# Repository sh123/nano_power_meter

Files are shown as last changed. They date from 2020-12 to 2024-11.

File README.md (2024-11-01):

# Introduction
Dual channel Arduino Nano RF milliwatt power meter for HF/VHF/UHF/SHF bands. Can be used for power measurement, different RF equipment troubleshooting, RF leakage search and antenna radiation/gain measurements and comparison.

This project is Arduino Nano clone of W1GHZ power meter adopted for use with Arduino Nano and SSD1307 OLED screen. Read more details at http://www.w1ghz.org/new/portable_powermeter.pdf.

Unlike original meter, which is just an indicator, this device shows precise dBm values and could be calibrated, calibration table is stored in the sketch. Moreover, device takes maximum RF power value during 1 second interval, which allows signal duration measurements down to 1 ms and marks maximum value during 1 minute interval on the bar.

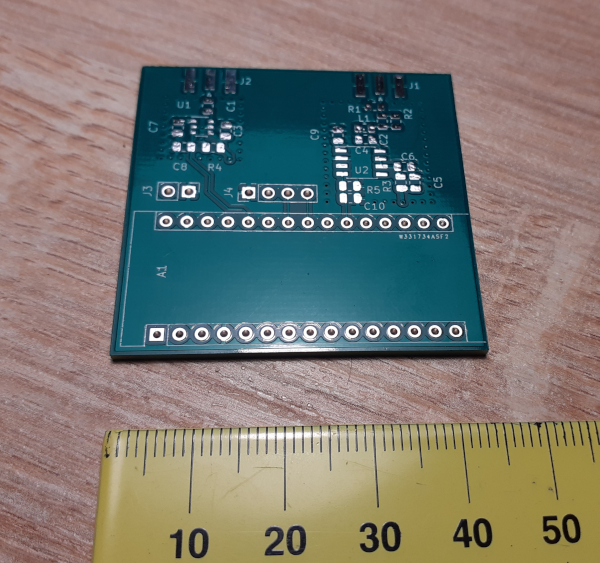
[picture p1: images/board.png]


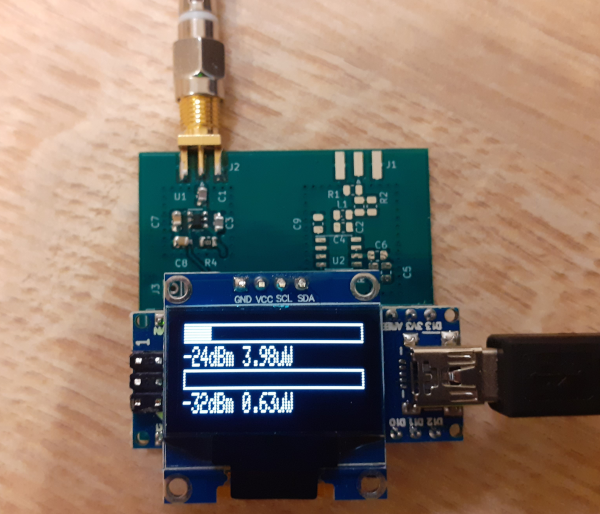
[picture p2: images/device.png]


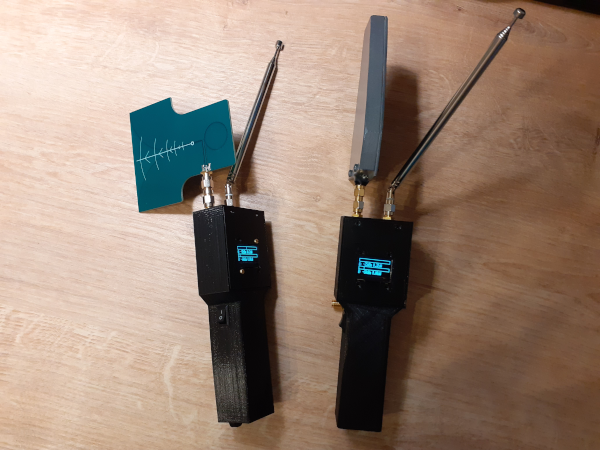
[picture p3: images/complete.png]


# Technical details
- Measurement power range from -32 up to 20 dBm on channel A and -60 up to 20 dBm on channel B, with external attenuator could be used for larger values.
- Frequency range
  - Channel A: 300 MHz - 7 GHz, up to 12 GHz with performance degradation
  - Channel B: 10 KHz up to 300 MHz
- Minimum signal length detection about 1 ms
- Based on Arduino Nano
- Screen is [SSD1307](https://cdn-shop.adafruit.com/datasheets/SSD1306.pdf)
- UHF/SHF part (left channel A) is based [LTC5507 RF Power Detector](https://www.analog.com/media/en/technical-documentation/data-sheets/5508fa.pdf), allows measurement from 300MHz up to 7GHz and up to approximately 12 GHz with some performance degradation.
- HF/VHF part (right channel B) is based on [AD8307 Logarithmic Amplifier](https://www.analog.com/media/en/technical-documentation/data-sheets/AD8307.pdf), allows mesurement from DC up to 300 MHz
- Geiger counter style buzzer for audiable signal level indication
- Must be powered from the battery (e.g. 9V)

# Building
User platformio to build and upload.

# Results
Sucessfully shows power values for various ISM signals, such as 5 GHz, 2.4 GHz WiFi, Bluetooth, 433/868 MHz ISM devices at close range and amateur radio transmissions at HF.

At SHF band good sensitivity and results are achieved when using cheap Vivaldi antenna. 

At HF/VHF/UHF telescopic antenna performs well enough. For close board inspection EM probes could be used. 

Also, additional shield could be helpful. 

Device must be powered from the battery only, powering from PC USB will cause PC USB RFI and other noise to be measured by the device.

Signals with larger than +20 dBm levels could be measured with additional external attenuator.

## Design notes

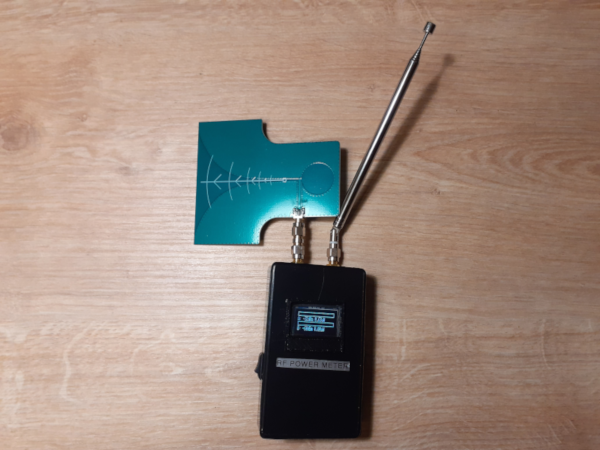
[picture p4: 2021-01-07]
images/devantennas.png

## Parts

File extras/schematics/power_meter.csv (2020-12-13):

Id | Designator | Package | Quantity | Designation | Supplier and ref
1 | A1 | Arduino_Nano | 1 | Arduino_Nano_v3.x
2 | C1 | C_0805_2012Metric | 1 | 8.2pF
3 | C2 | C_0805_2012Metric | 1 | 15pF
4 | C3,C7,C8,C10 | C_0805_2012Metric | 4 | 0.1uF
5 | C4 | C_0805_2012Metric | 1 | .01uF
6 | C5 | C_0805_2012Metric | 1 | 100pF
7 | C6,C9 | C_0805_2012Metric | 2 | C
8 | L1 | L_0805_2012Metric | 1 | L
9 | R1 | R_0805_2012Metric | 1 | 51
10 | R2,R3,R5 | R_0805_2012Metric | 3 | R
11 | R4 | R_0805_2012Metric | 1 | 10k
12 | U2 | SOIC-8_3.9x4.9mm_P1.27mm | 1 | ad8307
13 | J3 | PinHeader_1x02_P2.54mm_Vertical | 1 | Conn_01x02
14 | J4 | PinHeader_1x04_P2.54mm_Vertical | 1 | Conn_01x04
15 | J1 | SMA_Samtec_SMA-J-P-H-ST-EM1_EdgeMount | 1 | RF_UHF
16 | J2 | SMA_Samtec_SMA-J-P-H-ST-EM1_EdgeMount | 1 | RF_SHF
17 | U1 | TSOP-6_1.65x3.05mm_P0.95mm | 1 | ltc5508

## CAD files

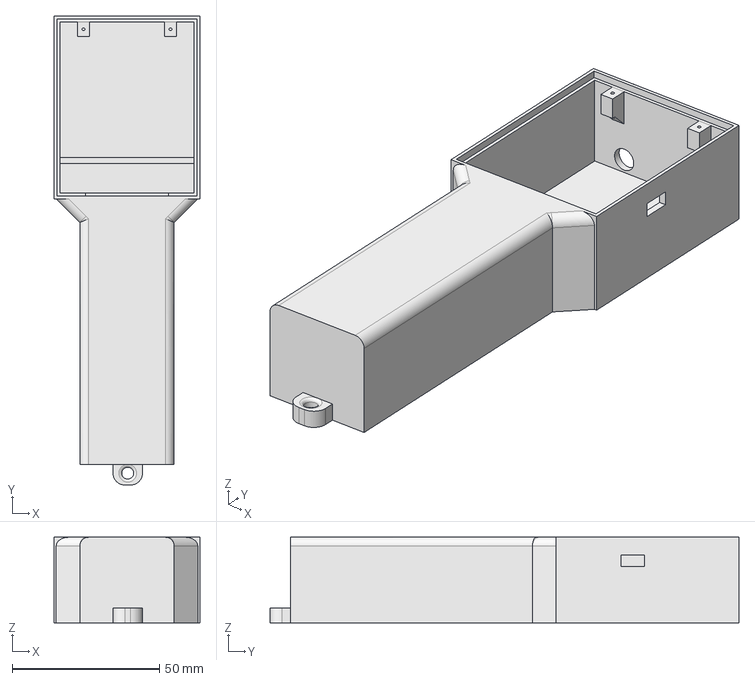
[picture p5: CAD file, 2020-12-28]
extras/case/power_meter_case.FCStd
49.5 x 159.0 x 29.0 mm

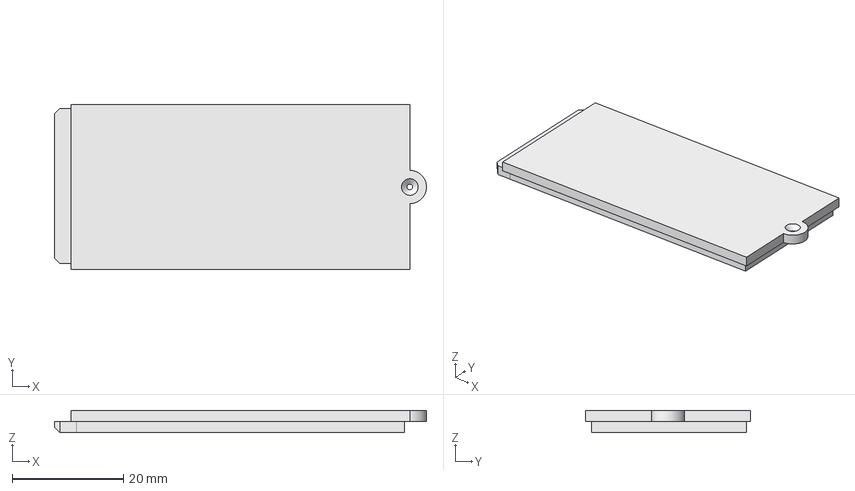
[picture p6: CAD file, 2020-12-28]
extras/case/power_meter_case_battery.FCStd
67.0 x 29.6 x 4.00 mm

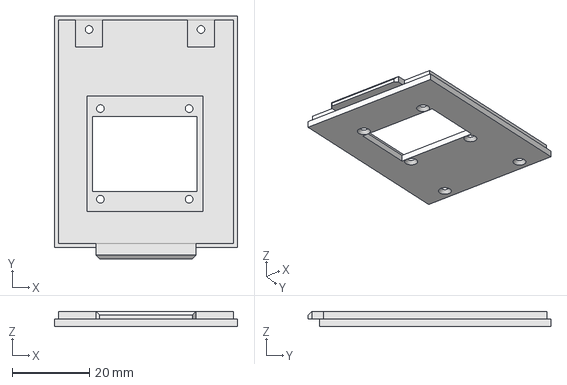
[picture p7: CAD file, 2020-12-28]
extras/case/power_meter_case_screen.FCStd
47.5 x 63.0 x 4.00 mm

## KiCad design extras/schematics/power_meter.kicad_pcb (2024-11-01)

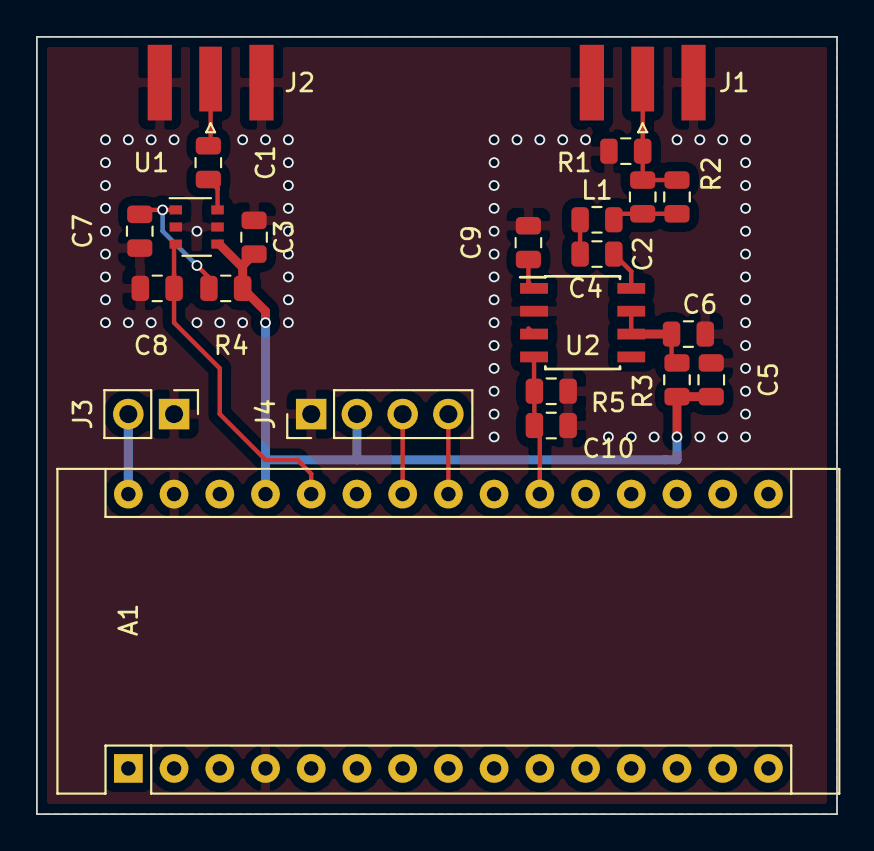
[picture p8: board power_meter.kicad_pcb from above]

Board: 2 copper layers, 44.5 x 43.2 mm, 23 parts (0 on the bottom side), 16 nets.

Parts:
A1: Arduino_Nano_v3.x; Arduino_Nano
C1: 8.2pF; C_0805_2012Metric
C2: 15pF; C_0805_2012Metric
C3, C7, C8, C10: 0.1uF; C_0805_2012Metric
C4: .01uF; C_0805_2012Metric
C5: 100pF; C_0805_2012Metric
C6, C9: C; C_0805_2012Metric
J1: RF_UHF; SMA_Samtec_SMA-J-P-H-ST-EM1_EdgeMount
J2: RF_SHF; SMA_Samtec_SMA-J-P-H-ST-EM1_EdgeMount
J3: Conn_01x02; PinHeader_1x02_P2.54mm_Vertical
J4: Conn_01x04; PinHeader_1x04_P2.54mm_Vertical
L1: L; L_0805_2012Metric
R1: 51; R_0805_2012Metric
R2, R3, R5: R; R_0805_2012Metric
R4: 10k; R_0805_2012Metric
U1: ltc5508; TSOP-6_1.65x3.05mm_P0.95mm
U2: ad8307; SOIC-8_3.9x4.9mm_P1.27mm

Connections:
+5V: A1.27, C3.2, C5.2, J4.2, R3.1, R4.2, U1.4
+9V: A1.30, J3.2
GND: A1.4, A1.29, C3.1, C5.1, C6.2, C7.2, C8.2, C9.1, C10.2, J1.2, J2.2, J3.1, J4.1, R1.2, R5.2, U1.2, U1.5, U2.2
unnamed: C1.1, J2.1
unnamed: C1.2, U1.6
unnamed: C2.1, L1.2, R2.1
unnamed: C2.2, J1.1, R1.1, R2.2
unnamed: C4.1, U2.8
unnamed: C4.2, L1.1
unnamed: C6.1, R3.2, U2.6, U2.7
unnamed: C7.1, R4.1, U1.1
unnamed: C9.2, U2.1
RF_SHF: A1.26, C8.1, U1.3
RF_UHF: A1.21, C10.1, R5.1, U2.4
SCL: A1.24, J4.3
SDA: A1.23, J4.4

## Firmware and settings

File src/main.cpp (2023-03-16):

#include <SPI.h>
#include <Wire.h>
#include <Adafruit_GFX.h>
#include <Adafruit_SSD1306.h>
#include <arduino-timer.h>

#define STARTUP_DELAY_MS 500

#define BAR_HEIGHT 7

#define SCREEN_WIDTH  128 // OLED display width, in pixels
#define SCREEN_HEIGHT 32  // OLED display height, in pixel

#define PIN_SHF A7
#define PIN_VHF A2
#define PIN_BUZZER 2

#define SCREEN_UPDATE_PERIOD_US 1000UL*1000UL
#define MEASURE_PERIOD_US       500UL
#define MEASURE_PERIOD_1M_US    60UL*1000UL*1000UL
#define BUZZER_PERIOD_US        100UL*1000UL

#define CALA_TABLE_SIZE 16
#define CALB_TABLE_SIZE 14

#define DEFAULT_VALUE_A 50
#define DEFAULT_VALUE_B 150

#define BUZZER_MAX_RATE 10
#define BUZZER_TONE 500
#define BUZZER_DURATION_MS 10
#define BUZZER_MIN_A_DBM -25
#define BUZZER_MIN_B_DBM -35

struct cal_t {
  int v;
  int dbm;
};

cal_t calA_[CALA_TABLE_SIZE] = {
  {  0,   -91 },
  { 21,   -51 },
  { 56,   -29 },
  { 59,   -25 },
  { 60,   -21 },
  { 63,   -17 },
  { 72,   -13 },
  { 102,   -9 },
  { 122,   -5 },
  { 143,   -1 },
  { 163,    3 },
  { 204,    7 },
  { 245,   11 },
  { 409,   15 },
  { 614,   23 },
  { 1024,  33 }
};

cal_t calB_[CALB_TABLE_SIZE] = {
  {   0,  -77 },
  {  80,  -67 },
  { 100,  -57 },
  { 150,  -47 },
  { 210,  -37 },
  { 290,  -27 },
  { 308,  -17 },
  { 330,   -7 },
  { 410,    3 },
  { 480,   13 },
  { 515,   23 },
  { 540,   33 },
  { 560,   43 }
};

int valueA_, valueB_, valueA_1M_, valueB_1M_;
unsigned int buzzerRate_, buzzerCounter_;

Timer<4, micros> timer_;

Adafruit_SSD1306 display_(SCREEN_WIDTH, SCREEN_HEIGHT, &Wire);

float toMw(int dbm) {
  return pow(10, (float)dbm / 10.0);
}

int toBarLengthA(int dbm) {
  double k = (double)(SCREEN_WIDTH) / (double)(calA_[CALA_TABLE_SIZE - 2].dbm - calA_[2].dbm);
  return k * (double)(dbm - calA_[2].dbm);
}

int toBarLengthB(int dbm) {
  double k = (double)(SCREEN_WIDTH) / (double)(calB_[CALB_TABLE_SIZE - 3].dbm - calB_[3].dbm);
  return k * (double)(dbm - calB_[3].dbm);
}

int toDbmA(int adValue) {
  int prevValue = calA_[0].v;
  int prevDbm = calA_[0].dbm;

  if (adValue <= prevValue) return prevDbm;
  
  for (int i = 1; i < CALA_TABLE_SIZE; i++) {
   if (adValue > prevValue && adValue <= calA_[i].v) {
     double k = (double)(calA_[i].dbm - prevDbm) / (double)(calA_[i].v - prevValue);
     return k * (double)(adValue - prevValue) + prevDbm;
   }
   prevValue = calA_[i].v;
   prevDbm = calA_[i].dbm;
  }
  return calA_[CALA_TABLE_SIZE - 1].dbm;
}

int toDbmB(int adValue) {
  int prevValue = calB_[0].v;
  int prevDbm = calB_[0].dbm;
  if (adValue <= prevValue) return prevDbm;
  
  for (int i = 1; i < CALB_TABLE_SIZE; i++) {
   if (adValue > prevValue && adValue <= calB_[i].v) {
     double k = (double)(calB_[i].dbm - prevDbm) / (double)(calB_[i].v - prevValue);
     return k * (adValue - prevValue) + prevDbm;
   }
   prevValue = calB_[i].v;
   prevDbm = calB_[i].dbm;
  }
  return calB_[CALB_TABLE_SIZE - 1].dbm;
}

int getBuzzerRate(int dbmA, int dbmB) {
  if (dbmA > BUZZER_MIN_A_DBM && dbmA > dbmB) {
    return -0.2 * (double)(dbmA + 30) + BUZZER_MAX_RATE;
  }
  else if (dbmB > BUZZER_MIN_B_DBM) {
    return -0.14 * (double)(dbmB + 50) + BUZZER_MAX_RATE;
  }
  else {
    return 0;
  }
}

bool printMeasuredValue(void *) {
  
  display_.clearDisplay();
  display_.setTextSize(1);

  // channel A
  int dbmA = toDbmA(valueA_);
  int dbmA_1M = toDbmA(valueA_1M_);
  float mwA = toMw(dbmA);
  
  display_.drawRect(0, 0, SCREEN_WIDTH, BAR_HEIGHT, SSD1306_WHITE);
  display_.fillRect(0, 0, toBarLengthA(dbmA), BAR_HEIGHT, SSD1306_WHITE);

  int barA_1M = toBarLengthA(dbmA_1M);
  display_.drawLine(barA_1M, 0, barA_1M, BAR_HEIGHT - 1, SSD1306_WHITE);

  display_.setCursor(0, BAR_HEIGHT + 1);
  display_.print("A: ");
  display_.print(dbmA);
  display_.print("dBm ");
  if (mwA >= 1) {
    display_.print(mwA);
    display_.print("mW ");
  } else {
    display_.print(mwA * 1000);
    display_.print("uW ");
  }

  // channel B
  int dbmB = toDbmB(valueB_);
  int dbmB_1M = toDbmB(valueB_1M_);
  float mwB = toMw(dbmB);
  
  display_.drawRect(0, 2 * BAR_HEIGHT + 2, SCREEN_WIDTH, BAR_HEIGHT, SSD1306_WHITE);
  display_.fillRect(0, 2 * BAR_HEIGHT + 2, toBarLengthB(dbmB), BAR_HEIGHT, SSD1306_WHITE);

  int barB_1M = toBarLengthB(dbmB_1M);
  display_.drawLine(barB_1M, 2 * BAR_HEIGHT + 2, barB_1M, 3 * BAR_HEIGHT + 1, SSD1306_WHITE);

  display_.setCursor(0, 3 * BAR_HEIGHT + 3);
  display_.print("B: ");
  display_.print(dbmB);
  display_.print("dBm ");
  if (mwB >= 1) {
    display_.print(mwB);
    display_.print("mW ");
  } else {
    display_.print(mwB * 1000);
    display_.print("uW ");
  }
  display_.display();
  valueA_ = DEFAULT_VALUE_A; 
  valueB_ = DEFAULT_VALUE_B;

  buzzerRate_ = getBuzzerRate(dbmA, dbmB);
  return true;
}

bool clean1MValue(void *) {
  valueA_1M_ = DEFAULT_VALUE_A;
  valueB_1M_ = DEFAULT_VALUE_B;
  return true;
}

bool buzzer(void *) {
  if (buzzerRate_ > 0 && buzzerCounter_ % buzzerRate_ == 0) {
    tone(PIN_BUZZER, BUZZER_TONE, BUZZER_DURATION_MS);
  }
  else {
    noTone(PIN_BUZZER);
  }
  buzzerCounter_++;
  return true;
}

bool measure(void *) {
  int vA = analogRead(PIN_SHF);
  if (vA > valueA_) {
    valueA_ = vA;
  }
  if (vA > valueA_1M_) {
    valueA_1M_ = vA;
  }
  int vB = analogRead(PIN_VHF);
  if (vB > valueB_) {
    valueB_ = vB;
  }
  if (vB > valueB_1M_) {
    valueB_1M_ = vB;
  }
  return true;
}

void setup() {
  Serial.begin(115200);
  while (!Serial);
  
  if(!display_.begin(SSD1306_SWITCHCAPVCC, 0x3C)) 
  {
    Serial.println(F("SSD1306 allocation failed"));
    for(;;);
  }

  display_.clearDisplay();
  display_.setTextSize(2);      // Normal 1:1 pixel scale
  display_.setTextColor(SSD1306_WHITE); // Draw white text
  display_.setCursor(8, 8);     // Start at top-left corner
  display_.print(F("PWR meter"));
  display_.display();
  delay(STARTUP_DELAY_MS);
  
  display_.clearDisplay();
  display_.display();

  valueA_ = valueA_1M_ = DEFAULT_VALUE_A;
  valueB_ = valueB_1M_ = DEFAULT_VALUE_B;
  buzzerRate_ = buzzerCounter_ = 0;

  pinMode(PIN_BUZZER, OUTPUT);
  
  timer_.every(MEASURE_PERIOD_1M_US, clean1MValue);
  timer_.every(SCREEN_UPDATE_PERIOD_US, printMeasuredValue);
  timer_.every(MEASURE_PERIOD_US, measure);
  timer_.every(BUZZER_PERIOD_US, buzzer);
}

void loop() {
  timer_.tick();
}

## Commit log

2020-12-13 Added schematics and Arduino sketch
    [power_meter.csv, power_meter.kicad_pcb, power_meter.sch]
2020-12-13 Updated missed component values
    [power_meter.sch]
2020-12-13 Update calibration table
2020-12-15 Change analog in pin for HF
2020-12-15 Fix bug with bar scale
    [nano_power_meter.ino]
2020-12-18 Added calibration for second channel
    [power_meter.sch]
2020-12-28 Added case
    [power_meter_case.FCStd, power_meter_case_battery.FCStd, power_meter_case_screen.FCStd]
2021-01-03 Add support for buzzer
    [nano_power_meter.ino]
2021-01-09 Implement periodic buzzer with lower period on higher signal
    [nano_power_meter.ino]
2021-01-12 Updated device image
2022-01-19 Updated calibration tables and minimum buzzer values
    [nano_power_meter.ino]
2023-03-16 Add gerber files
    [power_meter-B_Cu.gbl, power_meter-B_Mask.gbs, power_meter-B_Paste.gbp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]
2023-03-16 Moved project to platformio
    [power_meter-B_Cu.gbl, power_meter-B_Mask.gbs, power_meter-B_Paste.gbp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]
2024-11-01 Added missing files
    [power_meter.kicad_pcb, power_meter.kicad_sch]
